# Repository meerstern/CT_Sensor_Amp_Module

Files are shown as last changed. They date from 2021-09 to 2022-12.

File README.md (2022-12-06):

# CTセンサアンプ基板  
CT Sensor Amp Module

## 概要 
  * 本基板はクランプ式CTセンサの出力を増幅してRMS値(実効値)に変換する基板です  
  * 交流電流に応じたRMS値(実効値)をアナログ値(直流)として得ることができます  
  * シャント抵抗、RMS値の演算ICを搭載しているため、交流電流の実効値をアナログ値として得ることが可能です  
  * 実効値をアナログ値として得られるため、マイコン側での高サンプリングAD変換やRMS演算等が不要です  
  * CTセンサ入力アンプ[INA181A1アンプ][1]、RMS換算[LTC1966][2]、低オフセット出力アンプ[MCP6V62][3]を使用しています  
  * シャント抵抗は49.9Ω、10Ω、1Ω、0.3Ωの4種類から選択できます  
  * シャント抵抗、CTセンサによって異なりますが、最小0.1A~最大300A程度まで測定可能です(3.3V電源時)  
  * 基板サイズ25mm x30mm、固定穴M3x2 幅20mm
  
## 換算式
  INA181A1によるゲイン20倍、出力段アンプゲイン3倍で合計60倍の増幅率です  

  VOUT= (I x Gain x R)/CT  
  I = (VOUT x CT)/(Gain x R)  
  VOUT:アナログ出力電圧(V)、I:CTセンサ対象電流(A)、Gain:60倍(固定)、R:シャント抵抗(Ω)、CT:巻き線比  
  
  例　VOUT=(IxGainxR)/(CT比)=(Ix60x49.9)/3000   

## シャント抵抗と測定電流範囲目安
  * 1:3000のCTセンサを用いた場合の各シャント抵抗における最小電流と最大電流目安です    
  * 最大電流は増幅アンプ飽和の目安となる電圧から設定しています  
  * 最小電流はオフセット電圧が数10mV生じるため、影響を無視できる目安として設定しています  

| シャント抵抗 | 最小電流A(電源3.3V) | 最大電流A(電源3.3V) | 最小電流A(電源5V) | 最大電流A(電源5V) |
|:---|:---|:---|:---|:---|
| 49.9 | 0.1 | 3 | 0.1 | 5 |
| 10.0 | 0.5 | 15 |	0.5 |	23 |
| 1.0 |	5 | 150 | 5	| 230 |
| 0.3 |	10 | 340 | 10 | 500 |				
			 
## 注意 
  * CTセンサは同梱されていません  
  * 巻き線比1:2000~3000前後ののCTセンサを使用してください  
  * 使用時は必ずシャント抵抗のいずれか1つをジャンパさせてください  
  * CTセンサの特性上、活線で2次側を解放すると数kVの電圧が発生しCTの損傷や感電の恐れがあります  
  * CTの損傷や感電を防ぐため、出力保護素子を内蔵したCTセンサの使用を推奨します  
  * 電源は3.3V、5Vに対応していますが、5V電源の方がレンジを確保できるため、より多くの電流を測定できます  
  * 電源電圧以上の出力はアンプが飽和するため、正しく出力されません    
  * AD変換の入力インピーダンスやオフセット電圧等の影響で、電流0Aでも数10mV程度の出力電圧が生じます  
  * 各シャント抵抗における最小電流以下の小さな電流測定には向きません  
  * 50Hz/60Hzの商用電源の電流をCTセンサで測定する用途を想定しています  
  * RMS演算ICによって真の実効値演算を得ていますが、大きな歪みやノイズが多い場合、正しく測定できない場合があります  
  * 回路上のローパスフィルタで高周波をカットオフしているため、数百Hz以上の電流変化は測定できません  
  
 ## 販売サイト
  * [スイッチサイエンス][4]
  
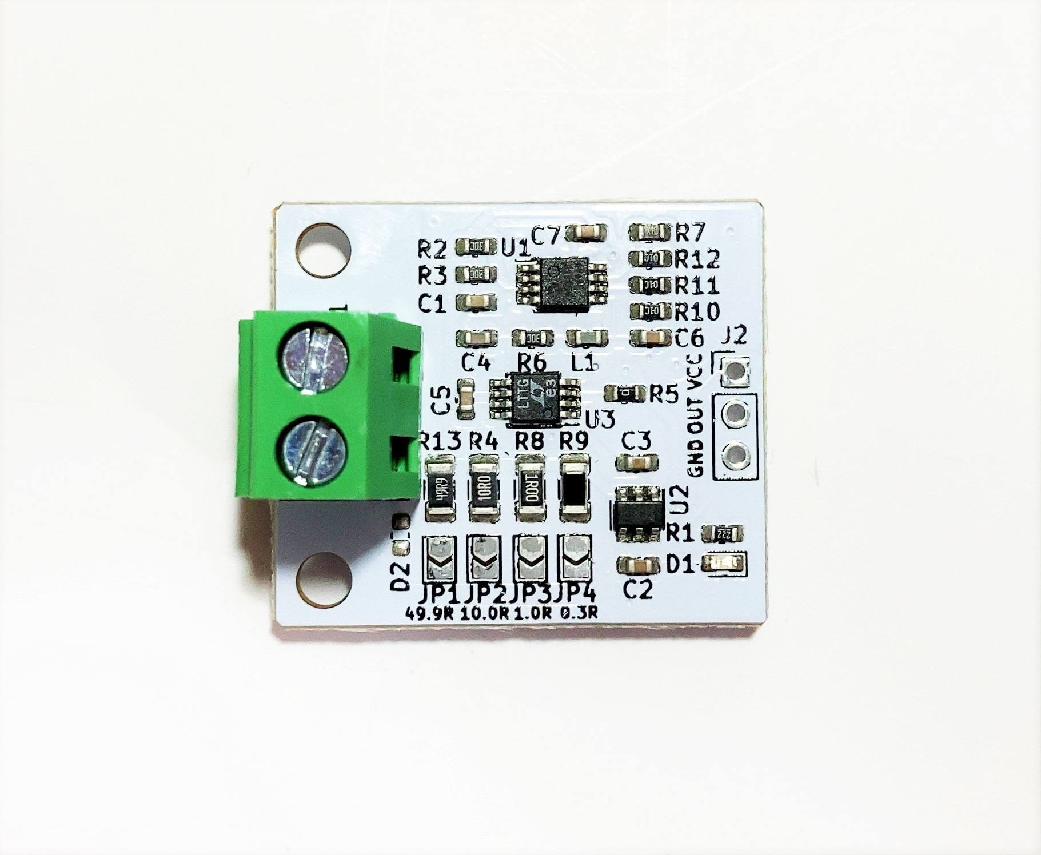
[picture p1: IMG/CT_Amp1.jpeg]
  
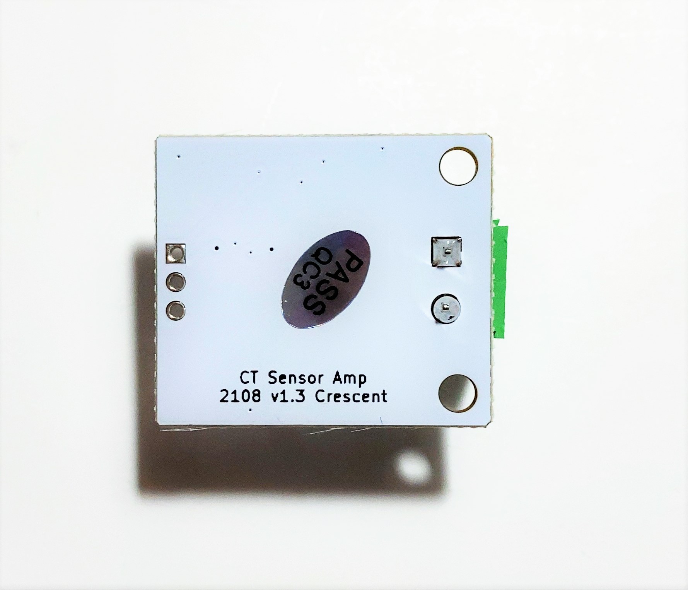
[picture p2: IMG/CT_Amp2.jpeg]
  

[1]: https://www.tij.co.jp/product/jp/INA181 "*1"
[2]: https://www.analog.com/jp/products/ltc1966.html "*2"
[3]: https://www.microchip.com/en-us/product/MCP6V62 "*3"
[4]: https://www.switch-science.com/products/7559

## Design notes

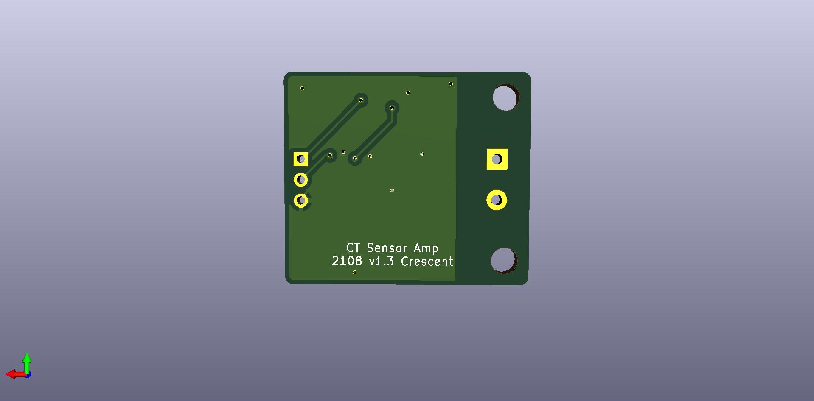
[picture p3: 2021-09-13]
PCB/csa2.jpg

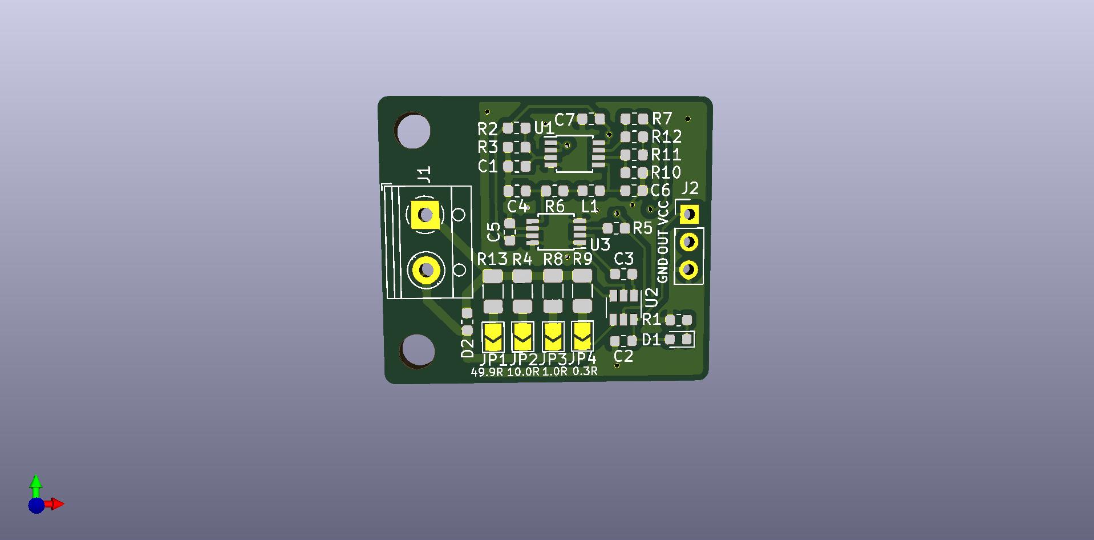
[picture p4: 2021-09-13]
PCB/csa1.jpg

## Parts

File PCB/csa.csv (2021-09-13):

ID | 参照記号 | パッケージ | 数 | 名称 | Supplier and ref
1 | H2,H1 | MountingHole_3.2mm_M3 | 2 | MountingHole
2 | U3 | TSSOP-8_3x3mm_P0.65mm | 1 | LTC1966
3 | U2 | SOT-23-6 | 1 | INA181A1
4 | U1 | TSSOP-8_3x3mm_P0.65mm | 1 | MCP6V62-E/MS
5 | R7 | R_0603_1608Metric | 1 | 10
6 | R6,R3,R2 | R_0603_1608Metric | 3 | 20k
7 | R5 | R_0603_1608Metric | 1 | 0
8 | R4 | R_1206_3216Metric | 1 | 10
9 | R1 | R_0603_1608Metric | 1 | 2k
10 | J2 | PinHeader_1x03_P2.54mm_Vertical | 1 | Conn_01x03
11 | J1 | TerminalBlock_RND_205-00012_1x02_P5.00mm_Horizontal | 1 | CT
12 | D2 | R_0603_1608Metric | 1 | D_TVS
13 | D1 | D_0603_1608Metric | 1 | LED
14 | C7,C6,C5,C3,C2,C1 | C_0603_1608Metric | 6 | 0.1u
15 | C4 | C_0603_1608Metric | 1 | 1u
16 | L1 | L_0603_1608Metric | 1 | FerriteBeads
17 | R8 | R_1206_3216Metric | 1 | 1
18 | R9 | R_1206_3216Metric | 1 | 0.2
19 | R10,R11,R12 | R_0603_1608Metric | 3 | 10k
20 | JP1,JP2,JP3 | SolderJumper-2_P1.3mm_Open_TrianglePad1.0x1.5mm | 3 | SolderJumper_2_Open

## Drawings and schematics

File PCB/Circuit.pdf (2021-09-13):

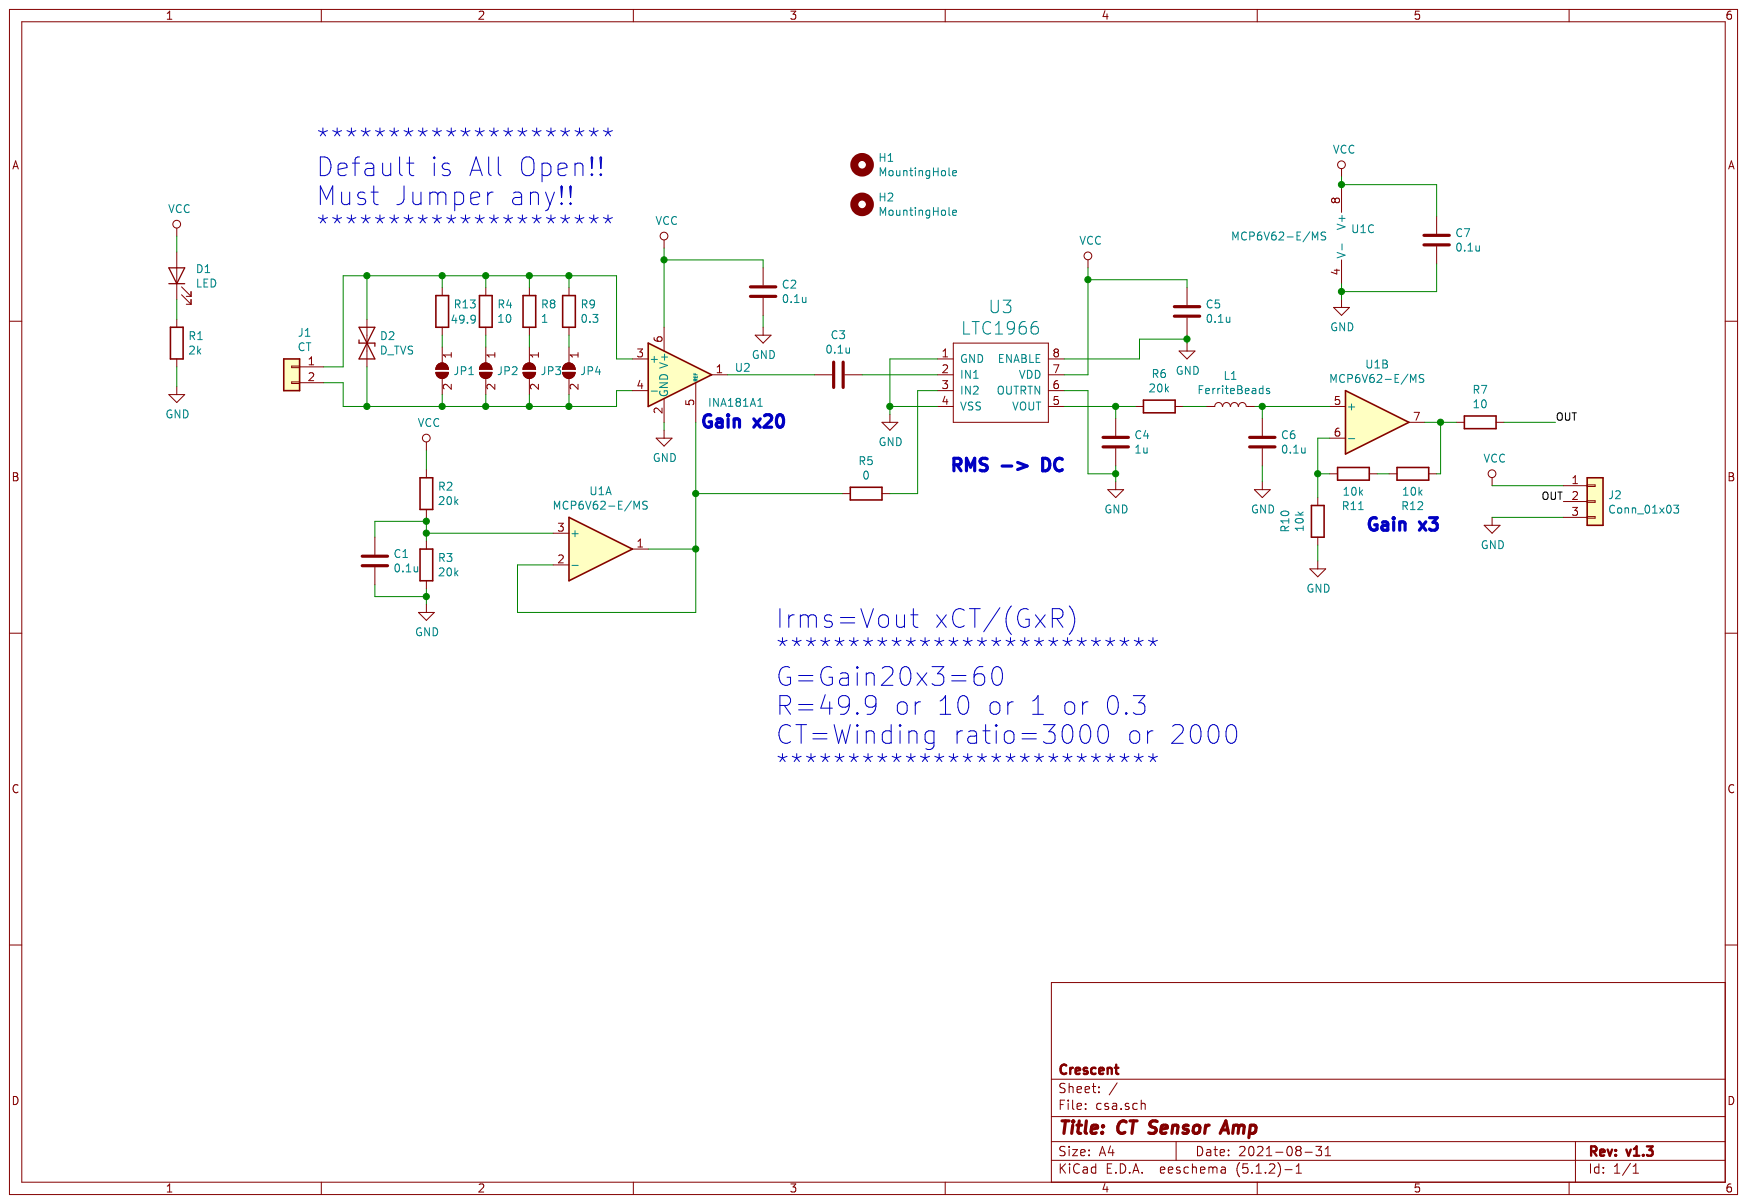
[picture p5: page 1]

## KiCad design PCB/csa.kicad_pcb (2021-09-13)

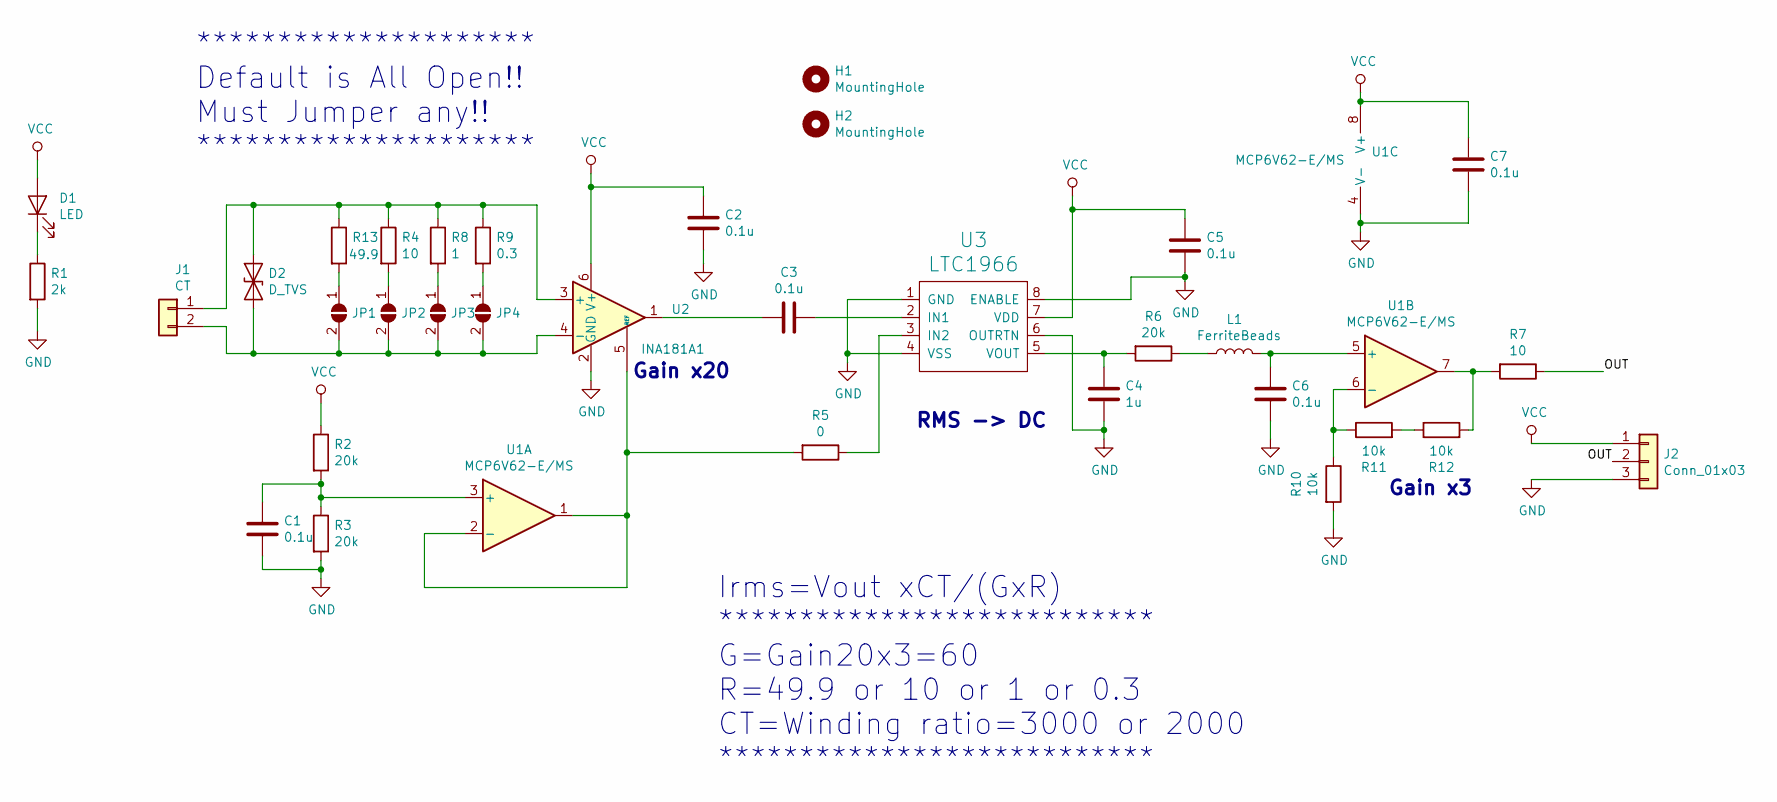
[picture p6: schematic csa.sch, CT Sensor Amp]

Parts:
C1, C2, C3, C5, C6, C7: 0.1u; C_0603_1608Metric
C4: 1u; C_0603_1608Metric
D1: LED; D_0603_1608Metric
D2: D_TVS; R_0603_1608Metric
H1, H2: MountingHole; MountingHole_3.2mm_M3
J1: CT; TerminalBlock_RND_205-00012_1x02_P5.00mm_Horizontal
J2: Conn_01x03; PinHeader_1x03_P2.54mm_Vertical
JP1, JP2, JP3, JP4: SolderJumper_2_Open; SolderJumper-2_P1.3mm_Open_TrianglePad1.0x1.5mm
L1: FerriteBeads; L_0603_1608Metric
R1: 2k; R_0603_1608Metric
R2, R3, R6: 20k; R_0603_1608Metric
R4: 10; R_1206_3216Metric
R5: 0; R_0603_1608Metric
R7: 10; R_0603_1608Metric
R8: 1; R_1206_3216Metric
R9: 0.3; R_1206_3216Metric
R10, R11, R12: 10k; R_0603_1608Metric
R13: 49.9; R_1206_3216Metric
U1: MCP6V62-E/MS; TSSOP-8_3x3mm_P0.65mm
U2: INA181A1; SOT-23-6
U3: LTC1966; TSSOP-8_3x3mm_P0.65mm

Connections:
/OUT: J2.2, R7.1
GND: C1.2, C2.2, C4.2, C5.2, C6.2, C7.2, J2.3, R1.2, R3.2, R10.2, U1.4 (V-), U2.2 (GND), U3.1 (GND), U3.4 (VSS), U3.6 (OUTRTN), U3.8 (ENABLE)
unnamed: C1.1, R2.2, R3.1, U1.3 (+)
unnamed: C3.1, U3.2 (IN1)
unnamed: C3.2, U2.1
unnamed: C4.1, R6.2, U3.5 (VOUT)
unnamed: C6.1, L1.2, U1.5 (+)
unnamed: D1.1 (K), R1.1
unnamed: D2.1 (A1), J1.1, R4.1, R8.1, R9.1, R13.1, U2.3 (+)
unnamed: D2.2 (A2), J1.2, JP1.2 (B), JP2.2 (B), JP3.2 (B), JP4.2 (B), U2.4 (-)
unnamed: JP1.1 (A), R13.2
unnamed: JP2.1 (A), R4.2
unnamed: JP3.1 (A), R8.2
unnamed: JP4.1 (A), R9.2
unnamed: L1.1, R6.1
unnamed: R5.1, U3.3 (IN2)
unnamed: R5.2, U1.1, U1.2 (-), U2.5 (REF)
unnamed: R10.1, R11.1, U1.6 (-)
unnamed: R11.2, R12.1
unnamed: R7.2, R12.2, U1.7
VCC: C2.1, C5.1, C7.1, D1.2 (A), J2.1, R2.1, U1.8 (V+), U2.6 (V+), U3.7 (VDD)

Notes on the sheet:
Gain x20
Gain x3
Irms=Vout xCT/(GxR) *************************** G=Gain20x3=60 R=49.9 or 10 or 1 or 0.3 CT=Winding ratio=3000 or 2000 ***************************
********************* Default is All Open!! Must Jumper any!! *********************
RMS -> DC

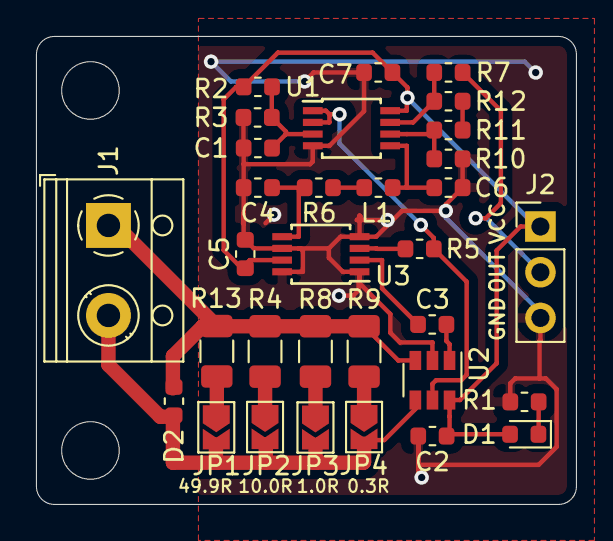
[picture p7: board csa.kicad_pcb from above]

Board: 2 copper layers, 30.0 x 26.0 mm, 34 parts (0 on the bottom side), 21 nets.
